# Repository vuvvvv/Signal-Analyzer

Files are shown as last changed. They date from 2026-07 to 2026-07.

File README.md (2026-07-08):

# Signal Analyzer محلل الاشارات
## RTL-SDR Radio Signal Analyzer with AI Detection

<p align="center">
  
</p>

<p align="center">
  
   &nbsp;&nbsp;
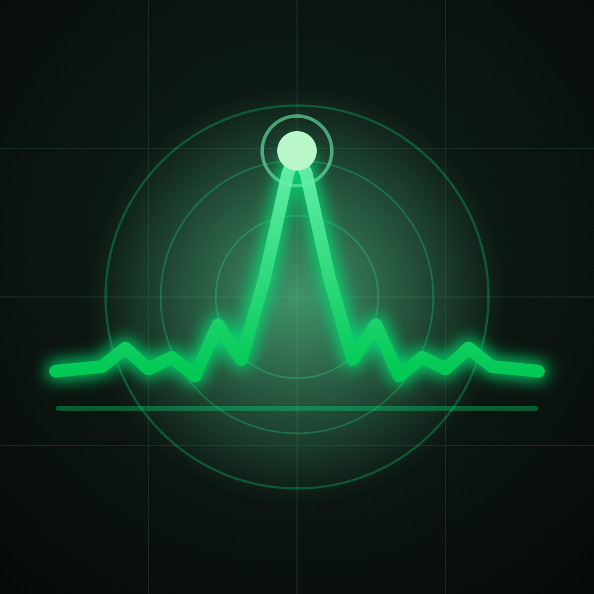
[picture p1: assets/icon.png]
  
   &nbsp;&nbsp;
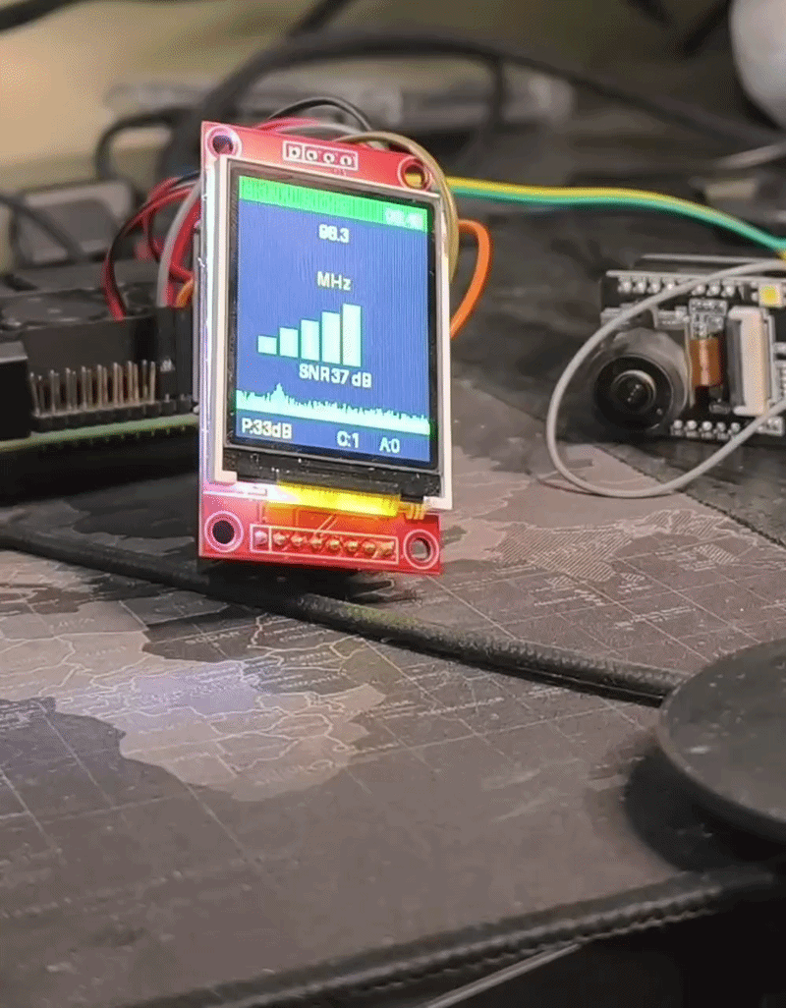
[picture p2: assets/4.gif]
  
</p>
<br><br>

Signal Analyzer is a real-time RF spectrum analyzer built with Flutter, Raspberry Pi, and an RTL SDR receiver. It transforms inexpensive RTL SDR hardware into a portable signal analyzer capable of scanning the RF spectrum, detecting and classifying signals with an AI powered anomaly engine, demodulating supported transmissions, and streaming live spectrum data and detections to a mobile application via WebSocket.

Designed for completely local operation, Signal Analyzer requires no cloud infrastructure, no API keys, and no internet connection. Every component from SDR acquisition and DSP processing to AI inference and visualization runs entirely on the Raspberry Pi and communicates with the Flutter app over your local Wi-Fi network, delivering fast, private, and reliable real-time analysis.

<table align="center">
<tr>
<td align="center">
<b></b><br>
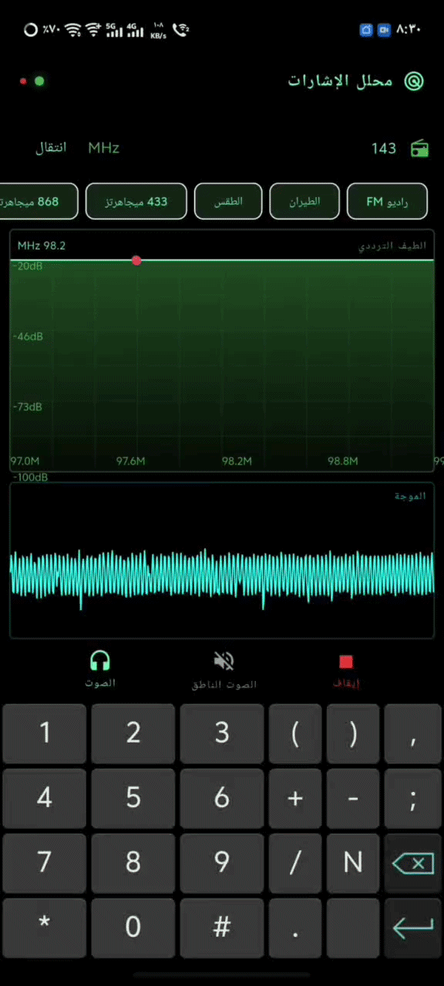
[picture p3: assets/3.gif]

</td>

</tr>
</table>

<br><br>

## Features

- 📊 **Live spectrum & waterfall** — real-time FFT streamed to the Flutter app (MessagePack over WebSocket)
- 🤖 **AI signal detection** — IsolationForest anomaly scoring + band-aware technology matching (Wi-Fi, BLE, LoRa, FM, airband, pagers…)
- 🔊 **On-Pi audio** — WFM / NFM / AM / USB / LSB via a patched `rtl_fm`, CW via `csdr`; audio plays on the Pi's own output
- 🎙️ **Audio classification & Speech-To-Text** — optional TFLite audio classifier and Vosk STT (CPU-only, degrade gracefully if models are missing)
- 🗂️ **RF band database** — table-driven catalogue of allocations, no station names, overlaps handled
- 🖥️ **ST7735 dashboard** — 1.8" LCD on the Pi shows status and alerts, plus a GPIO status LED
- 📼 **IQ capture** — record and compare captures, served over a built-in HTTP endpoint

<br><br>

## How It Works

1. `SdrReader` owns the single RTL-SDR handle and streams raw IQ
2. IQ fans out through drop-oldest queues to the **audio**, **spectrum**, and **AI** workers — no stage can ever block another
3. CPU-heavy AI work (anomaly retraining, audio classification, STT) runs in **separate OS processes** so it never steals time from the real-time path
4. The asyncio event loop pushes results to the Flutter app: AI detections are never dropped, spectrum frames are throttled to only the newest
5. Audio is demodulated and played **on the Pi itself** — no PCM ever crosses the WebSocket, the app only sends control commands

```
SdrReader (RTL-SDR)
   ├── AudioWorker ──► rtl_fm_pipe / csdr ──► Pi speaker
   │        └── AudioClassifierWorker / SttWorker (processes)
   └── SpectrumWorker ──► AiWorker (process, IsolationForest)
                └──► WebSocket ──► Flutter app 📱
```

<br><br>

## Hardware Required

| Component | Model / Spec |
| --- | --- |
| Single-board computer | **Raspberry Pi** (any model with GPIO) |
| SDR receiver | **RTL-SDR dongle** (RTL2832U based) |
| Display | **ST7735 — 1.8 inch — 128×160 pixels** |
| Status LED | Any LED on **GPIO 18** (Pin 12) |
| Audio output | Pi's 3.5mm jack / USB audio (played via `sox`) |
| Phone | Any device running the Flutter app |
| Network | Shared Wi-Fi router **or** phone hotspot |

<br>

## Wiring — ST7735 → Raspberry Pi

| ST7735 Pin | Function | Pi GPIO (BCM) | Notes |
| --- | --- | --- | --- |
| VCC | Power | 3.3V | ⚠️ 3.3V only — never 5V |
| GND | Ground | GND | Common ground |
| SCL / SCLK | SPI Clock | GPIO 11 | Hardware SPI |
| SDA / MOSI | SPI Data | GPIO 10 | Hardware SPI |
| CS | Chip Select  | GPIO 8 | CE0 |
| DC / RS | Data/Command | GPIO 24 | |
| RES / RST  | Reset | GPIO 25 | |
| LED | Status LED | GPIO 18 | Pin 12, with resistor |

💡 The screen runs in **portrait mode (128×160)** and the install script enables hardware SPI for you.

<br><br>

## Raspberry Pi Setup

### 1. Install everything

```bash
cd backend
chmod +x install.sh
./install.sh
```

The script installs system packages, blacklists the DVB kernel driver, enables SPI, builds `csdr` and `rtl_fm_pipe` from source, and sets up the Python venv.

### 2. (Optional) AI extras

Drop the models in `backend/models/` to unlock the extra features — everything works without them:

```
backend/models/audio_classifier.tflite   # audio classification
backend/models/vosk-model-small/         # Speech-To-Text button
```

### 3. Run the server

```bash
source venv/bin/activate
python signal_server.py
```

The WebSocket server listens on port **8765**.

### Prebuilt Modules

Three modules of the analyzer ship as **precompiled native extensions** (`.so`) instead of Python source: `signal_analyzer`, `channel_id`, and `fingerprint_store`. Everything else in the backend is open source — you can read it, modify it, and extend it freely.

Nothing extra to do: the `.so` files are already in `backend/` and Python imports them automatically. `install.sh` verifies they load on your Pi. They are built for **Raspberry Pi OS (64-bit)** with its stock Python — if the check fails on your setup (different architecture or Python version), open an issue with your `uname -m` and `python3 -V` output.

<br><br>

## Flutter App Setup

<table align="center">
<tr>
<td align="center">
<b>الرئيسيه</b><br>
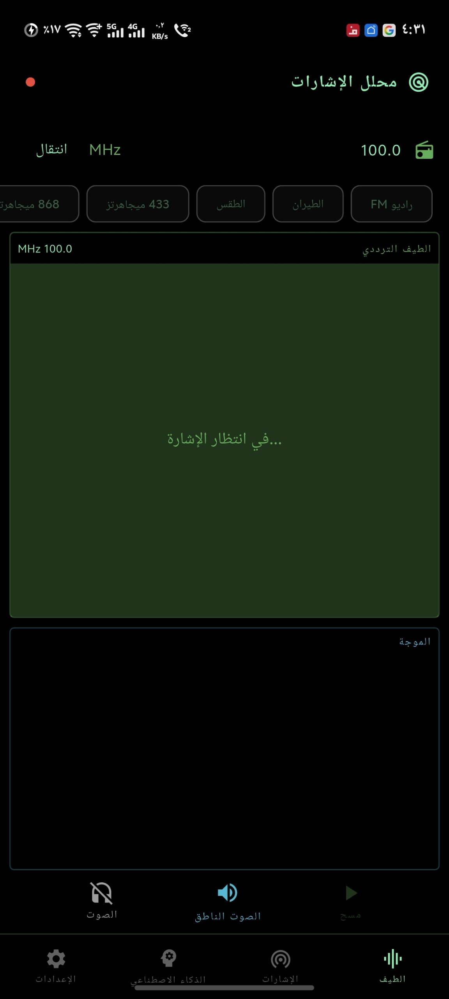
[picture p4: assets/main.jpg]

</td>

<td align="center">
<b>Ai </b><br>
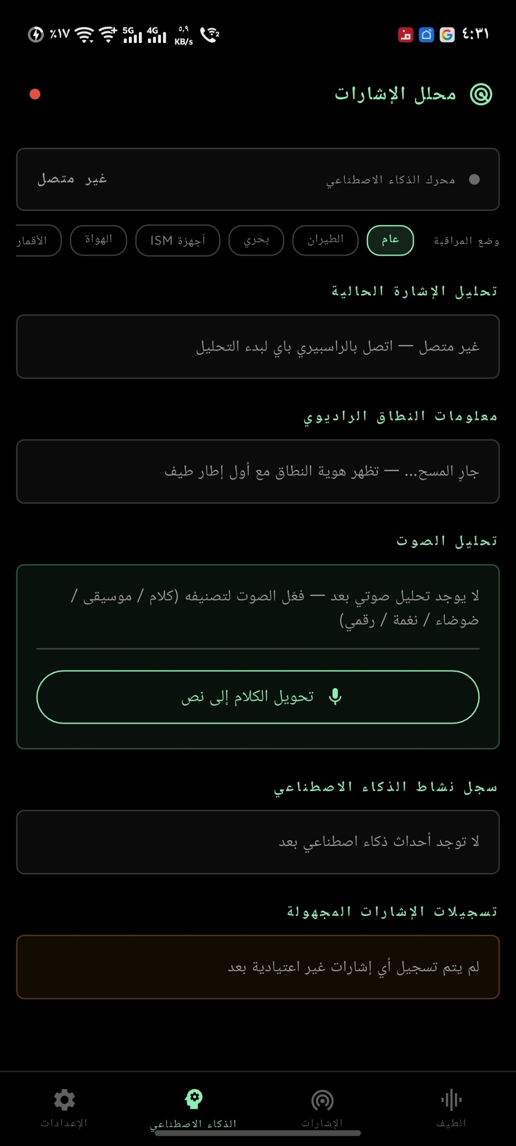
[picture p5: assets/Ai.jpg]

</td>

<td align="center">
<b>الاشارة</b><br>
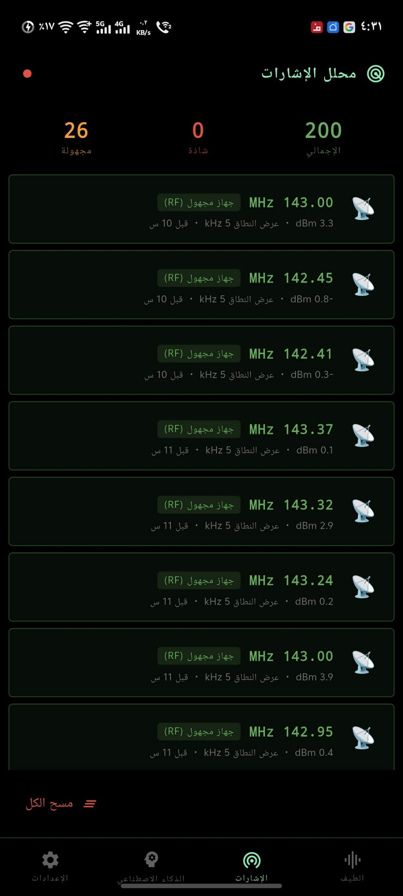
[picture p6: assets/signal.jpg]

</td>

<td align="center">
<b>الاعدادات</b><br>
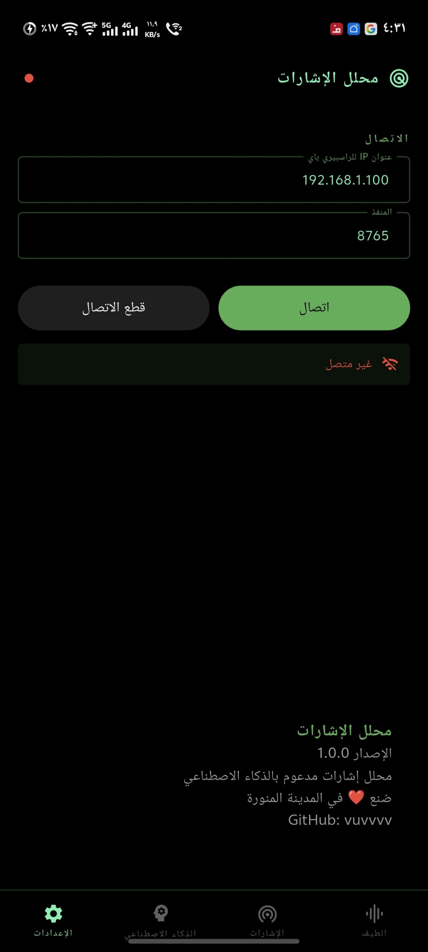
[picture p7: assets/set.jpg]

</td>
</tr>
</table>

<br><br>

### 1. Build & install

```bash
flutter pub get
flutter run
```

### 2. Connect

Open the **Settings** tab and enter your Pi's IP with port `8765`, then start scanning. The **Spectrum**, **Signals**, and **AI** tabs update in real time — with local notifications and TTS alerts for high-priority detections.

<br><br>

## App Screens

| Tab | What it shows |
| --- | --- |
| 📊 Spectrum  | Live FFT / waterfall, frequency tuning, demodulator + audio controls |
| 📡 Signals | Detected signals with band, technology, and SNR |
| 🤖 AI | Anomaly scores, audio classification, Speech-To-Text, captures |
| ⚙️ Settings  | Pi connection, alerts, preferences |

<br><br>

## Pi Server Protocol

| Message | Direction | Description |
| --- | --- | --- |
| `set_freq` | app → Pi | Tune to a frequency |
| `set_demodulator` | app → Pi | WFM / NFM / AM / USB / LSB / CW |
| `start_audio` / `stop_audio` | app → Pi | Toggle on-Pi audio playback |
| `set_volume` / `mute` / `unmute` | app → Pi | Audio control |
| `start_stt` / `stop_stt` | app → Pi  | Toggle Speech-To-Text |
| spectrum / waveform  | Pi → app | Throttled, newest-frame-only |
| AI detections | Pi → app | Priority — never dropped |
<br><br>

## 3D Print Files

A printable enclosure for the Pi + ST7735 build, found in the [`3D/`](3D/) folder:

- [`signalbox.stl`](3D/signalbox.stl) — main box
- [`signalcaver.stl`](3D/signalcaver.stl) — cover

<p align="center">
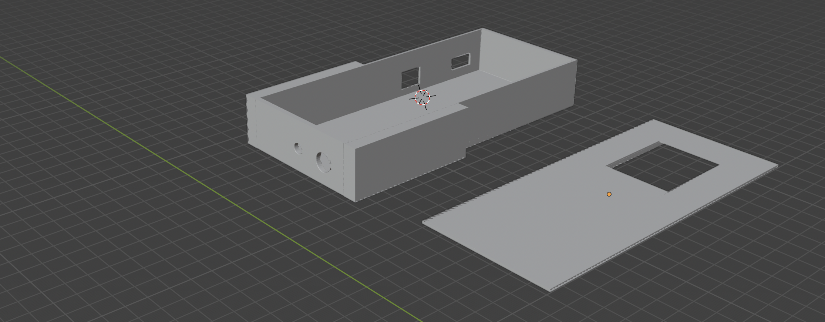
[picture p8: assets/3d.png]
  
</p>

<br><br>

## Project Structure

```
SignalـAnalyzer/
├── 3D/                           # 3D-printable enclosure
│   ├── signalbox.stl             # main box
│   └── signalcaver.stl           # cover
├── lib/                          # Flutter app
│   ├── main.dart
│   ├── screens/
│   │   ├── home_screen.dart
│   │   ├── spectrum_screen.dart
│   │   ├── signals_screen.dart
│   │   ├── ai_screen.dart
│   │   └── settings_screen.dart
│   ├── services/
│   │   └── sdr_service.dart      # WebSocket + msgpack client
│   ├── models/
│   ├── utils/
│   └── widgets/
│       └── spectrum_painter.dart
├── backend/                      # Raspberry Pi server
│   ├── signal_server.py          # WebSocket server + pipeline
│   ├── sdr_reader.py             # RTL-SDR IQ reader
│   ├── spectrum_worker.py        # FFT
│   ├── ai_worker.py              # IsolationForest (own process)
│   ├── signal_analyzer.so        # signal classification engine (prebuilt, closed-source)
│   ├── channel_id.so             # channel/band identity (prebuilt, closed-source)
│   ├── fingerprint_store.so      # signal fingerprint memory (prebuilt, closed-source)
│   ├── band_db.py                # RF allocation database
│   ├── audio_worker.py           # demod pipeline
│   ├── rtl_fm_chain.py           # WFM/NFM/AM/USB/LSB via rtl_fm_pipe
│   ├── csdr_chain.py             # CW via csdr
│   ├── audio_classifier_worker.py
│   ├── stt_worker.py             # Vosk Speech-To-Text
│   ├── capture_manager.py        # IQ captures
│   ├── screen_controller.py      # ST7735 dashboard
│   ├── led_controller.py         # status LED
│   ├── vendor/rtl_fm_pipe.c      # patched rtl_fm (stdin IQ)
│   └── install.sh
└── assets/
```

<br><br>

<p align="center">
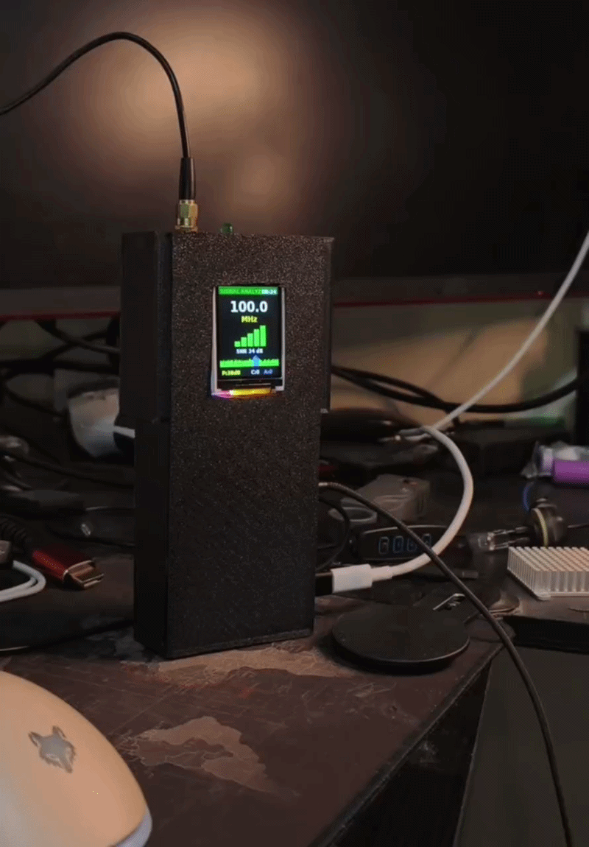
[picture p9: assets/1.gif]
  
</p>

[@vuvvvv](https://github.com/vuvvvv)

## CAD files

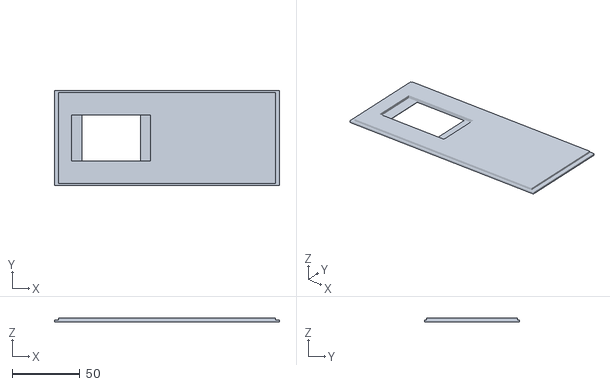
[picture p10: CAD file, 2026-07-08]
3D/signalcaver.stl
165.7 x 70.1 x 3.12

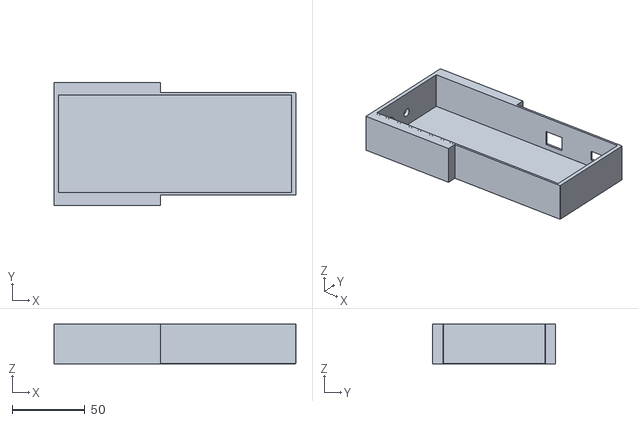
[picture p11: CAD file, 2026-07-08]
3D/signalbox.stl
165.8 x 84.0 x 27.2

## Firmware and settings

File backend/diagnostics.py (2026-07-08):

#!/usr/bin/env python3
"""Standalone diagnostic tool for the FM receive chain (RF -> SDR config ->
IQ samples -> DSP -> audio).

This is intentionally separate from the live server: it opens the RTL-SDR
directly (same device, same settings as `sdr_reader.py`, but no threads,
no queues, no WebSocket) and measures real numbers at every stage so a fix
can be based on measurement instead of guesswork. Run it while the server
(signal_server.py) is stopped, since only one process can hold the dongle.

Usage:
    python3 diagnostics.py --freq 94.0
    python3 diagnostics.py --freq 94.0 --gains auto,20.7,40.2 --ppm 0 --demod WFM
    python3 diagnostics.py --freq 94.0 --out report.json
"""

import argparse
import json
import sys
import time

import numpy as np
from scipy import signal as dsp_signal

from dsp import get_demodulator
from dsp.filters import estimate_carrier_offset
from stage_profiler import StageProfiler

DEFAULT_GAINS = ["auto", 0, 8.7, 19.7, 28.0, 33.8, 40.2, 49.6]
CHANNEL_HALF_BW_HZ = 100_000.0  # matches WFMDemodulator.channel_bw_hz
OFFSET_SEARCH_HALF_BW_HZ = 300_000.0  # wider window: tuner LO error can be hundreds of kHz


def open_sdr(freq_hz: float, sample_rate: float, gain, ppm: int):
    from rtlsdr import RtlSdr

    sdr = RtlSdr()
    sdr.sample_rate = sample_rate
    sdr.center_freq = freq_hz
    if ppm:
        sdr.freq_correction = ppm
    try:
        sdr.gain = gain
    except Exception as e:
        print(f"  ! gain {gain!r} rejected ({e}), falling back to auto")
        sdr.gain = "auto"

    actual = {
        "requested": {"sample_rate": sample_rate, "center_freq": freq_hz, "gain": gain, "ppm": ppm},
        "actual": {
            "sample_rate": sdr.sample_rate,
            "center_freq": sdr.center_freq,
            "gain": sdr.gain,
            "freq_correction": sdr.freq_correction,
        },
    }
    return sdr, actual


def analyze_iq(iq: np.ndarray) -> dict:
    i, q = iq.real, iq.imag
    clip_thresh = 0.98
    clipping_pct = 100.0 * np.mean((np.abs(i) >= clip_thresh) | (np.abs(q) >= clip_thresh))
    dc_i, dc_q = float(np.mean(i)), float(np.mean(q))
    rms_i, rms_q = float(np.sqrt(np.mean(i ** 2))), float(np.sqrt(np.mean(q ** 2)))
    imbalance_db = 20 * np.log10(rms_i / rms_q) if rms_q > 0 else float("inf")
    corr = float(np.corrcoef(i, q)[0, 1]) if np.std(i) > 0 and np.std(q) > 0 else 0.0
    return {
        "clipping_pct": round(clipping_pct, 3),
        "dc_offset_i": round(dc_i, 5),
        "dc_offset_q": round(dc_q, 5),
        "rms_i": round(rms_i, 5),
        "rms_q": round(rms_q, 5),
        "iq_imbalance_db": round(imbalance_db, 2),
        "iq_correlation": round(corr, 4),
    }


def analyze_spectrum(iq: np.ndarray, sample_rate: float, freq_hz: float) -> dict:
    freqs, psd = dsp_signal.welch(iq, fs=sample_rate, nperseg=4096, return_onesided=False)
    freqs = np.fft.fftshift(freqs)
    psd_db = 10 * np.log10(np.fft.fftshift(psd) + 1e-20)

    noise_floor_db = float(np.percentile(psd_db, 20))
    peak_idx = int(np.argmax(psd_db))
    peak_db = float(psd_db[peak_idx])
    peak_freq_offset_hz = float(freqs[peak_idx])
    snr_db = peak_db - noise_floor_db

    in_channel = np.abs(freqs) <= CHANNEL_HALF_BW_HZ
    weights = np.clip(psd_db[in_channel] - noise_floor_db, 0, None)
    if weights.sum() > 0:
        centroid_offset_hz = float(np.sum(freqs[in_channel] * weights) / weights.sum())
    else:
        centroid_offset_hz = 0.0
    suggested_ppm = centroid_offset_hz / freq_hz * 1e6

    # wider search: the strongest carrier may sit hundreds of kHz from the
    # requested center (tuner LO error / quirk), well outside one channel
    wide_offset_hz = estimate_carrier_offset(iq, sample_rate, OFFSET_SEARCH_HALF_BW_HZ) or 0.0

    return {
        "noise_floor_db": round(noise_floor_db, 2),
        "peak_power_db": round(peak_db, 2),
        "wide_search_carrier_offset_hz": round(wide_offset_hz, 1),
        "snr_db": round(snr_db, 2),
        "peak_offset_from_center_hz": round(peak_freq_offset_hz, 1),
        "channel_centroid_offset_hz": round(centroid_offset_hz, 1),
        "suggested_ppm_correction": round(suggested_ppm, 2),
    }


def gain_sweep(freq_hz: float, sample_rate: float, ppm: int, candidate_gains: list) -> list:
    results = []
    for gain in candidate_gains:
        try:
            sdr, _ = open_sdr(freq_hz, sample_rate, gain, ppm)
            iq = sdr.read_samples(64 * 1024)
            sdr.close()
        except Exception as e:
            results.append({"gain": gain, "error": str(e)})
            continue

        power_dbfs = 10 * np.log10(np.mean(np.abs(iq) ** 2) + 1e-20)
        iq_stats = analyze_iq(iq)
        spec_stats = analyze_spectrum(iq, sample_rate, freq_hz)
        results.append({
            "gain": gain,
            "power_dbfs": round(float(power_dbfs), 2),
            "clipping_pct": iq_stats["clipping_pct"],
            "snr_db": spec_stats["snr_db"],
        })
        time.sleep(0.05)
    return results


def audio_diagnostics(sdr, sample_rate: float, demod_name: str, n_chunks: int = 40, chunk_size: int = 8192) -> dict:
    demod = get_demodulator(demod_name)
    demod._build_state(sample_rate)
    warmup = max(5, n_chunks // 4)

    # mirror AudioWorker's one-shot lock: estimate once up front from a real
    # capture, then hold it fixed for the rest of the run (no per-chunk re-lock)
    first_iq = sdr.read_samples(chunk_size)
    offset = estimate_carrier_offset(first_iq, sample_rate, OFFSET_SEARCH_HALF_BW_HZ) or 0.0
    demod.set_freq_offset(offset)
    print(f"  locked carrier offset: {offset:+.0f} Hz")

    discriminator_samples = []
    post_process_samples = []
    pcm_samples = []

    for chunk_idx in range(n_chunks):
        iq = first_iq if chunk_idx == 0 else sdr.read_samples(chunk_size)
        centered = demod._mixer.process(iq)
        filtered = demod._channel_filter.process(centered)
        decimated = filtered[:: demod._decim_factor]
        intermediate_rate = sample_rate / demod._decim_factor

        raw_demod = demod._demodulate(decimated, intermediate_rate)
        post = demod._post_process(raw_demod, intermediate_rate)
        resampled = demod._resampler.process(post)
        pcm = np.clip(resampled * 32767, -32768, 32767).astype(np.int16)

        if chunk_idx >= warmup:
            discriminator_samples.append(raw_demod)
            post_process_samples.append(post)
            pcm_samples.append(pcm)

    disc = np.concatenate(discriminator_samples) if discriminator_samples else np.array([0.0])
    post_all = np.concatenate(post_process_samples) if post_process_samples else np.array([0.0])
    pcm_all = np.concatenate(pcm_samples) if pcm_samples else np.array([0], dtype=np.int16)
    pcm_f = pcm_all.astype(np.float64) / 32767.0

    silence_thresh = 0.01
    clip_thresh = 32760

    return {
        "demodulator": demod.name,
        "discriminator_rms": round(float(np.sqrt(np.mean(disc ** 2))), 5),
        "discriminator_peak": round(float(np.max(np.abs(disc))), 5),
        "post_process_rms": round(float(np.sqrt(np.mean(post_all ** 2))), 5),
        "post_process_peak": round(float(np.max(np.abs(post_all))), 5),
        "audio_rms": round(float(np.sqrt(np.mean(pcm_f ** 2))), 5),
        "audio_peak": int(np.max(np.abs(pcm_all))),
        "clipping_pct": round(100.0 * np.mean(np.abs(pcm_all) >= clip_thresh), 3),
        "silence_pct": round(100.0 * np.mean(np.abs(pcm_f) < silence_thresh), 2),
    }


def chunk_size_sweep(
    freq_hz: float,
    sample_rate: float,
    demod_name: str = "WFM",
    gain=40.2,
    ppm: int = 0,
    sizes: tuple = (2048, 4096, 8192),
    duration_s: float = 3.0,
    queue_depth: int = 3,
) -> list:
    """Measures, not guesses: for each candidate IQ chunk size, runs the
    real demodulator on real captures for `duration_s` seconds and reports
    per-chunk DSP latency (Avg/Max/p99), CPU usage (DSP-time / chunk
    duration — over 1.0 means the chunk can't be processed in real time),
    and how many chunks a drop-oldest queue of depth `queue_depth` would
    have to drop if AudioWorker fell behind by that amount."""
    results = []
    for chunk_size in sizes:
        sdr, _ = open_sdr(freq_hz, sample_rate, gain, ppm)
        demod = get_demodulator(demod_name)
        demod._build_state(sample_rate)

        first_iq = sdr.read_samples(chunk_size)
        offset = estimate_carrier_offset(first_iq, sample_rate, OFFSET_SEARCH_HALF_BW_HZ) or 0.0
        demod.set_freq_offset(offset)

        chunk_duration_s = chunk_size / sample_rate
        profiler = StageProfiler(window=10_000)
        n_chunks = max(1, int(duration_s / chunk_duration_s))
        max_clip = 0
        total_samples = 0

        for i in range(n_chunks):
            iq = first_iq if i == 0 else sdr.read_samples(chunk_size)
            t0 = time.perf_counter()
            pcm = demod.process(iq, sample_rate)
            profiler.record("dsp", time.perf_counter() - t0)
            max_clip += int(np.sum(np.abs(pcm) >= 32760))
            total_samples += len(pcm)

        sdr.close()
        stats = profiler.stats("dsp") or {}
        cpu_ratio = stats.get("avg_ms", 0) / 1000.0 / chunk_duration_s if chunk_duration_s else 0.0
        # simulate how often a queue of this depth would have to drop a
        # chunk if processing fell behind by p99 instead of average
        behind_chunks = max(0, int((stats.get("p99_ms", 0) / 1000.0) // chunk_duration_s))
        simulated_drops = max(0, behind_chunks - queue_depth)

        results.append({
            "chunk_size": chunk_size,
            "chunk_duration_ms": round(chunk_duration_s * 1000, 3),
            "dsp_avg_ms": round(stats.get("avg_ms", 0), 4),
            "dsp_max_ms": round(stats.get("max_ms", 0), 4),
            "dsp_p99_ms": round(stats.get("p99_ms", 0), 4),
            "cpu_ratio": round(cpu_ratio, 3),  # >1.0 means it can't keep up in real time
            "simulated_drops_per_run": simulated_drops,
            "clipping_samples": max_clip,
            "total_audio_samples": total_samples,
            "n_chunks_tested": n_chunks,
        })
        print(f"  chunk_size={chunk_size}: {results[-1]}")
    return results


def print_report(report: dict) -> None:
    print("\n== RTL-SDR Config (requested vs actual) ==")
    print(json.dumps(report["sdr_config"], indent=2))

    print("\n== IQ Sample Health ==")
    print(json.dumps(report["iq_health"], indent=2))

    print("\n== Spectrum / Frequency Offset ==")
    print(json.dumps(report["spectrum"], indent=2))

    print("\n== Gain Sweep ==")
    for row in report["gain_sweep"]:
        print(f"  {row}")

    print("\n== Audio Pipeline Diagnostics ==")
    print(json.dumps(report["audio"], indent=2))


def main() -> int:
    parser = argparse.ArgumentParser(description="FM receive chain diagnostics")
    parser.add_argument("--freq", type=float, required=True, help="frequency in MHz")
    parser.add_argument("--sample-rate", type=float, default=2.4e6)
    parser.add_argument("--gain", default=40.2, help="gain for the main capture ('auto' or a dB value)")
    parser.add_argument("--gains", default=None, help="comma-separated gain list for the sweep")
    parser.add_argument("--ppm", type=int, default=0)
    parser.add_argument("--demod", default="WFM")
    parser.add_argument("--out", default=None, help="optional path to save the report as JSON")
    parser.add_argument(
        "--chunk-sweep", action="store_true",
        help="measure DSP latency/CPU/clipping across IQ chunk sizes 2048/4096/8192 and exit",
    )
    args = parser.parse_args()

    freq_hz = args.freq * 1e6
    gain = args.gain
    if isinstance(gain, str) and gain != "auto":
        gain = float(gain)

    if args.chunk_sweep:
        print(f"Running chunk-size sweep at {args.freq} MHz (2048/4096/8192)...")
        try:
            sweep = chunk_size_sweep(freq_hz, args.sample_rate, args.demod, gain, args.ppm)
        except Exception as e:
            print(f"Failed to run chunk-size sweep: {e}", file=sys.stderr)
            return 1
        print("\n== Chunk Size Sweep ==")
        print(json.dumps(sweep, indent=2))
        if args.out:
            with open(args.out, "w") as f:
                json.dump({"chunk_sweep": sweep}, f, indent=2)
            print(f"\nSaved report to {args.out}")
        return 0

    print(f"Opening RTL-SDR at {args.freq} MHz, sample_rate={args.sample_rate:.0f}, gain={gain}, ppm={args.ppm}...")
    try:
        sdr, sdr_config = open_sdr(freq_hz, args.sample_rate, gain, args.ppm)
    except Exception as e:
        print(f"Failed to open RTL-SDR: {e}", file=sys.stderr)
        return 1

    print("Capturing IQ block for spectrum/IQ-health analysis...")
    iq_block = sdr.read_samples(2 ** 18)
    iq_health = analyze_iq(iq_block)
    spectrum = analyze_spectrum(iq_block, args.sample_rate, freq_hz)

    if args.gains:
        candidate_gains = [g if g == "auto" else float(g) for g in args.gains.split(",")]
    else:
        candidate_gains = DEFAULT_GAINS
    print(f"Running gain sweep over {candidate_gains}...")
    sweep = gain_sweep(freq_hz, args.sample_rate, args.ppm, candidate_gains)

    print(f"Running audio pipeline diagnostics with demodulator={args.demod}...")
    audio = audio_diagnostics(sdr, args.sample_rate, args.demod)

    sdr.close()

    report = {
        "sdr_config": sdr_config,
        "iq_health": iq_health,
        "spectrum": spectrum,
        "gain_sweep": sweep,
        "audio": audio,
    }
    print_report(report)

    if args.out:
        with open(args.out, "w") as f:
            json.dump(report, f, indent=2)
        print(f"\nSaved report to {args.out}")

    return 0


if __name__ == "__main__":
    sys.exit(main())

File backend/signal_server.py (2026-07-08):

#!/usr/bin/env python3
"""
Signal Scope Backend - Raspberry Pi WebSocket Server

Architecture (real-time pipeline, see README in this directory for the
full writeup):

    SdrReader (thread)          -- blocking RTL-SDR reads, nothing else
        |-- audio_queue   (drop-oldest, depth N) --> AudioWorker (thread) --> LocalAudioSink
        |-- spectrum_slot (drop-oldest, depth 1) --> SpectrumWorker (thread)
                                                          |-- ai_in_queue (drop-oldest, depth 1) --> AiWorker (PROCESS)

    There is exactly one RTL-SDR handle, owned by SdrReader, open for as
    long as scanning is active. Audio and spectrum/AI both read off that
    same IQ stream, so spectrum/search and audio always run together —
    starting/stopping audio never touches the device.

    AudioWorker also taps its finished PCM (only while audio is actually
    enabled) into ai_audio_queue (drop-oldest, depth 1) which feeds
    AudioClassifierWorker (a second, separate PROCESS) and, only when a
    client explicitly asked for it, SttWorker.

    Every worker hands its finished output to this module via a plain
    callback, which bridges it onto the asyncio event loop
    (`loop.call_soon_threadsafe`). The event loop owns a single prioritized
    sender: AI detections are sent as soon as they arrive and are never
    dropped; spectrum/waveform are throttled and always reflect only the
    newest frame, since stale visuals aren't worth the bandwidth. Audio
    classification results and captures are lower priority still — see
    `_sender_loop`.

No stage can block another: the reader never waits on a queue (drop-oldest
everywhere upstream of it), and CPU-heavy AI work (RF anomaly retraining,
audio classification, speech-to-text) all run in separate processes/
threads so none of it can steal GIL time from the SDR/spectrum/audio/
network real-time path. Every AI-adjacent stage is a pure consumer: if it
falls behind, its queue just drops old data — it can never block or slow
down the pipeline feeding it.

Audio is *not* streamed to clients. AudioWorker (audio_worker.py) feeds IQ
into rtl_fm_pipe (rtl_fm_chain.py — a patched, otherwise-unmodified build
of rtl-sdr's own rtl_fm.c) for WFM/NFM/AM/USB/LSB, and into csdr
(csdr_chain.py) for CW (the one mode real rtl_fm has no -M for). No
demodulator is written for this project; PCM is written straight to
LocalAudioSink, which plays it on the Pi's own audio output via a local
`play` subprocess. Flutter only ever sends control commands (start_audio/
stop_audio/set_freq/set_demodulator/set_volume/mute/unmute) — no PCM
crosses the WebSocket.
"""

from __future__ import annotations

import asyncio
import logging
import os
import queue
import threading
import time
from datetime import datetime

import msgpack
import numpy as np
import websockets

from ai_worker import AiWorker
from audio_classifier_worker import AudioClassifierWorker
from audio_worker import AudioWorker
from capture_manager import CaptureManager
from captures_http import CapturesHttpServer
from droppable_queue import drain_queue, put_dropping_oldest
from led_controller import LedController
from local_audio import LocalAudioSink
from screen_controller import ScreenController
from sdr_reader import SdrReader
from spectrum_worker import SpectrumWorker
from stt_worker import SttWorker

logging.basicConfig(level=logging.INFO)
log = logging.getLogger(__name__)

HOST = "0.0.0.0"
PORT = 8765
# 2.4 MS/s (old value) sits near the FC0013's practical USB/ADC limit —
# confirmed via a side-by-side IQ capture (iq_compare.py) on this exact
# hardware/antenna/station: same carrier-lock accuracy, same DC-spike
# size, but measurably (and audibly) noisier than capturing at 1.02 MS/s —
# the rate rtl_fm itself uses on this dongle ("Sampling at 1020000 S/s" in
# its own log).
SAMPLE_RATE = 1_020_000.0
# Hard tuner limits for THIS dongle's FC0013: asking librtlsdr for a
# frequency the PLL can't lock (e.g. 949 MHz) doesn't just fail — it
# leaves the device in a bad state and the process segfaults. Reject
# out-of-range requests before they ever reach the hardware.
# Override via SIGNAL_SCOPE_TUNER_RANGE="14:948" (MHz) for other tuners.
_range = os.environ.get("SIGNAL_SCOPE_TUNER_RANGE", "14:948").split(":")
TUNER_MIN_MHZ, TUNER_MAX_MHZ = float(_range[0]), float(_range[1])
NUM_SAMPLES = 8 * 1024  # ~8.0ms/chunk at this rate — matches rtl_fm's own "Buffer size: 8.03ms"
AUDIO_QUEUE_DEPTH = 3  # ~25ms of look-ahead before the reader drops audio chunks
VIZ_SEND_INTERVAL = 1 / 12  # spectrum/waveform refresh rate sent to clients


class SdrServer:
    def __init__(self):
        self.led = LedController(gpio_pin=18)
        self.screen = ScreenController()
        self.clients: set = set()
        self.loop: asyncio.AbstractEventLoop | None = None

        # Cross-thread hand-off queues
        self.audio_in_queue: "queue.Queue" = queue.Queue(maxsize=AUDIO_QUEUE_DEPTH)
        self.spectrum_slot: "queue.Queue" = queue.Queue(maxsize=1)
        self.ai_audio_queue: "queue.Queue" = queue.Queue(maxsize=1)  # AudioWorker -> audio tap bridge

        # Outbound (asyncio-side) state
        self.signal_out: asyncio.Queue = asyncio.Queue()
        self.status_out: asyncio.Queue = asyncio.Queue()
        self.audio_ai_out: asyncio.Queue = asyncio.Queue()  # lowest priority: audio class. + captures
        self._latest_spectrum: dict | None = None
        self._latest_waveform: dict | None = None
        self._latest_audio_pcm: bytes | None = None
        self._wake_event: asyncio.Event | None = None

        _gain_override = os.environ.get("SIGNAL_SCOPE_GAIN")
        _gain = _gain_override if _gain_override == "auto" else (float(_gain_override) if _gain_override else 40.2)
        self.reader = SdrReader(
            SAMPLE_RATE, NUM_SAMPLES, self.audio_in_queue, self.spectrum_slot, gain=_gain
        )
        self.audio_sink = LocalAudioSink()
        self.audio_worker = AudioWorker(
            SAMPLE_RATE, self.audio_in_queue, self.audio_sink, ai_tap_queue=self.ai_audio_queue
        )
        self.ai_worker = AiWorker(self._on_detection)
        # SpectrumWorker feeds the AI process directly: its mp.Queue
        # (maxsize=1, drop-oldest via put_dropping_oldest) IS the ai_in
        # slot. There is no intermediate plain Queue — a previous refactor
        # left one in between with nothing consuming it, which silently
        # starved the RF analyzer of every frame.
        self.ai_in_queue = self.ai_worker.in_queue
        self.spectrum_worker = SpectrumWorker(
            self.spectrum_slot, self.ai_in_queue, self._on_spectrum, self._on_waveform
        )
        self.audio_classifier_worker = AudioClassifierWorker(self._on_audio_classification)
        self.capture_manager = CaptureManager()
        self.stt_worker = SttWorker(self._on_stt_text)
        self.captures_http = CapturesHttpServer(self.capture_manager.base_dir)
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

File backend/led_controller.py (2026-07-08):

"""LED Controller - GPIO18 (Pin 12)

Aircraft-beacon style: brightness ramps up and down smoothly using PWM,
like a plane's beacon light. If software PWM is unavailable (some Pi 5 /
rpi-lgpio setups), falls back to plain on/off blinking so the LED always
works. Pulsing runs on a background thread so callers never block.
"""

import math
import threading
import time
import logging

log = logging.getLogger(__name__)

try:
    import RPi.GPIO as GPIO
    _HAS_GPIO = True
except ImportError:
    _HAS_GPIO = False
    log.warning("RPi.GPIO not available (not on Pi?)")


class LedController:
    PWM_FREQ = 200        # Hz, flicker-free
    FADE_STEPS = 80       # brightness steps per fade in/out (more = smoother)

    def __init__(self, gpio_pin: int = 18):
        self.pin = gpio_pin
        self._pwm = None
        self._lock = threading.Lock()
        self._pulses_pending = 0
        self._beacon = False
        self._pulse_interval = 0.5
        self._stop = threading.Event()
        self._wake = threading.Event()
        if _HAS_GPIO:
            GPIO.setmode(GPIO.BCM)
            GPIO.setup(self.pin, GPIO.OUT, initial=GPIO.LOW)
            try:
                self._pwm = GPIO.PWM(self.pin, self.PWM_FREQ)
                self._pwm.start(0)
                # Verify PWM actually accepts duty changes; some backends
                # only fail here, not at construction.
                self._pwm.ChangeDutyCycle(0)
                log.info("LED: software PWM active (smooth beacon mode)")
            except Exception as e:
                log.warning(f"LED: PWM unavailable ({e}), using on/off fallback")
                self._pwm = None
        self._thread = threading.Thread(target=self._run, name="led-pulse", daemon=True)
        self._thread.start()
        # Startup self-test: one visible pulse confirms wiring/config
        self.blink(times=1, interval=0.3)

    def _set_brightness(self, percent: float):
        if not _HAS_GPIO:
            return
        try:
            if self._pwm:
                self._pwm.ChangeDutyCycle(max(0.0, min(100.0, percent)))
            else:
                GPIO.output(self.pin, GPIO.HIGH if percent >= 50 else GPIO.LOW)
        except Exception as e:
            log.error(f"LED: set brightness failed: {e}")

    def on(self):
        self._set_brightness(100)

    def off(self):
        self._set_brightness(0)

    def blink(self, times: int = 1, interval: float = 0.2):
        """Queue smooth beacon pulses; returns immediately."""
        with self._lock:
            self._pulses_pending += times
            self._pulse_interval = interval
        self._wake.set()

    def start_beacon(self, interval: float = 1.2):
        """Pulse continuously (aircraft beacon) until stop_beacon()."""
        with self._lock:
            self._beacon = True
            self._pulse_interval = interval
        self._wake.set()

    def stop_beacon(self):
        with self._lock:
            self._beacon = False
        self.off()

    def _run(self):
        while not self._stop.is_set():
            self._wake.wait()
            if self._stop.is_set():
                break
            with self._lock:
                beacon = self._beacon
                if not beacon and self._pulses_pending <= 0:
                    self._wake.clear()
                    continue
                if not beacon:
                    self._pulses_pending -= 1
                interval = self._pulse_interval
            try:
                self._pulse(fade_time=max(interval, 0.15))
            except Exception as e:
                log.error(f"LED: pulse failed: {e}")

    def _pulse(self, fade_time: float):
        """One smooth breath: sine ramp 0 -> 100 -> 0 over 2*fade_time.
        In fallback (no PWM) mode this degrades to a clean on/off blink."""
        if self._pwm is None:
            self._set_brightness(100)
            time.sleep(fade_time)
            self._set_brightness(0)
            time.sleep(fade_time)
            return
        step_delay = fade_time / self.FADE_STEPS
        # Full breath as one cosine cycle: eased at both the dark and
        # bright ends, then squared (gamma) so the fade looks linear to
        # the eye — LEDs otherwise appear to snap on early in the ramp.
        total = self.FADE_STEPS * 2
        for i in range(total + 1):
            if self._stop.is_set():
                return
            level = (1 - math.cos(math.pi * i / self.FADE_STEPS)) / 2  # 0->1->0
            self._set_brightness(100 * level * level)
            time.sleep(step_delay)
        # Clear dark gap so the LED visibly rests fully off between breaths
        time.sleep(fade_time * 0.5)

    def cleanup(self):
        self._stop.set()
        self._wake.set()
        self._thread.join(timeout=2)
        if _HAS_GPIO:
            try:
                if self._pwm:
                    self._pwm.stop()
            finally:
                GPIO.cleanup(self.pin)

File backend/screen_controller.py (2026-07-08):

"""
ST7735 Screen Controller — PORTRAIT mode (128x160)
Wiring: VCC=3.3V, GND, CLK=GPIO11, MOSI=GPIO10, CS=GPIO8, DC=GPIO24, RST=GPIO25

Layout (top to bottom):
  - Header bar: app name + clock
  - Big frequency readout (large font) + "MHz"
  - Signal-strength bars (phone-style, from spectrum SNR) + dB value
  - Mini spectrum strip
  - Info lines: peak power, clients connected, anomaly count
"""

import logging
import time
from datetime import datetime

log = logging.getLogger(__name__)

try:
    from luma.core.interface.serial import spi
    from luma.lcd.device import st7735
    from PIL import Image, ImageDraw, ImageFont
    _HAS_LCD = True
except ImportError:
    _HAS_LCD = False
    log.warning("luma.lcd not available")

_FONT_PATHS = [
    "/usr/share/fonts/truetype/dejavu/DejaVuSans-Bold.ttf",
    "/usr/share/fonts/truetype/dejavu/DejaVuSans.ttf",
]


def _load_font(size: int):
    for path in _FONT_PATHS:
        try:
            return ImageFont.truetype(path, size)
        except Exception:
            continue
    return ImageFont.load_default()


class ScreenController:
    # Portrait: panel's native 128x160 orientation
    WIDTH = 128
    HEIGHT = 160

    DASHBOARD_INTERVAL = 1.0  # seconds between dashboard redraws
    ALERT_HOLD = 4.0          # keep an alert on screen this long before dashboard resumes

    def __init__(self):
        self.device = None
        self._last_dashboard = 0.0
        self._alert_until = 0.0
        self._anomaly_count = 0
        if _HAS_LCD:
            try:
                serial = spi(port=0, device=0, gpio_DC=24, gpio_RST=25)
                # Panel native geometry is 160x128 (proven working config).
                # rotate=1 turns it 90° so the framebuffer becomes 128x160
                # portrait — do NOT swap width/height here, luma does that.
                self.device = st7735(
                    serial, width=self.HEIGHT, height=self.WIDTH, rotate=1, bgr=True
                )
                log.info("ST7735 screen initialized (portrait 128x160)")
            except Exception as e:
                log.error(f"Screen init failed: {e}")
        if _HAS_LCD:
            self._font_big = _load_font(26)
            self._font_med = _load_font(14)
            self._font_small = _load_font(10)

    def _make_image(self) -> tuple:
        img = Image.new("RGB", (self.WIDTH, self.HEIGHT), "black")
        draw = ImageDraw.Draw(img)
        return img, draw

    def _display(self, img):
        if self.device:
            self.device.display(img)

    def _center_x(self, draw, text: str, font) -> int:
        w = draw.textlength(text, font=font)
        return int((self.WIDTH - w) / 2)

    def show_boot(self):
        if not _HAS_LCD:
            return
        img, draw = self._make_image()
        draw.text((self._center_x(draw, "SIGNAL", self._font_big), 40),
                  "SIGNAL", font=self._font_big, fill="green")
        draw.text((self._center_x(draw, "ANALYZER", self._font_big), 70),
                  "ANALYZER", font=self._font_big, fill="green")
        draw.text((self._center_x(draw, "Ready", self._font_small), 110),
                  "Ready", font=self._font_small, fill=(0, 180, 0))
        now = datetime.now().strftime("%H:%M:%S")
        draw.text((self._center_x(draw, now, self._font_small), 125),
                  now, font=self._font_small, fill="gray")
        self._display(img)

    # ---- main live view -------------------------------------------------

    def show_dashboard(self, powers: list, center_mhz: float, clients: int = 0):
        """Portrait dashboard. Throttled internally — safe to call at spectrum rate."""
        if not _HAS_LCD:
            return
        now = time.monotonic()
        if now < self._alert_until or now - self._last_dashboard < self.DASHBOARD_INTERVAL:
            return
        self._last_dashboard = now

        img, draw = self._make_image()

        # Header bar
        draw.rectangle([(0, 0), (self.WIDTH - 1, 13)], fill=(0, 40, 0))
        draw.text((3, 2), "SIGNAL ANALYZER", font=self._font_small, fill="green")
        clock = datetime.now().strftime("%H:%M")
        draw.text((self.WIDTH - draw.textlength(clock, font=self._font_small) - 3, 2),
                  clock, font=self._font_small, fill="white")

        # Big frequency readout
        freq_txt = f"{center_mhz:.1f}"
        draw.text((self._center_x(draw, freq_txt, self._font_big), 20),
                  freq_txt, font=self._font_big, fill="white")
        draw.text((self._center_x(draw, "MHz", self._font_med), 50),
                  "MHz", font=self._font_med, fill=(0, 200, 255))

        # Signal strength: SNR = peak above median noise floor
        peak_db = snr = 0.0
        bars = 0
        if powers:
            sorted_p = sorted(powers)
            noise = sorted_p[len(sorted_p) // 2]
            peak_db = max(powers)
            snr = peak_db - noise
            for th in (3, 8, 15, 22, 30):
                if snr >= th:
                    bars += 1

        # Phone-style bars (5 bars, increasing height)
        bx, base_y = 32, 106
        for i in range(5):
            h = 8 + i * 7
            x0 = bx + i * 14
            box = [(x0, base_y - h), (x0 + 10, base_y)]
            if i < bars:
                color = "red" if bars <= 1 else ("yellow" if bars <= 2 else "lime")
                draw.rectangle(box, fill=color)
            else:
                draw.rectangle(box, outline=(60, 60, 60))
        snr_txt = f"SNR {snr:.0f} dB"
        draw.text((self._center_x(draw, snr_txt, self._font_small), 109),
                  snr_txt, font=self._font_small, fill="white")

        # Mini spectrum strip
        strip_top, strip_h = 122, 20
        if powers:
            n = len(powers)
            min_p = min(powers)
            rng = max(max(powers) - min_p, 1)
            for x in range(self.WIDTH):
                idx = int(x * n / self.WIDTH)
                norm = (powers[idx] - min_p) / rng
                bar = int(norm * strip_h)
                draw.line([(x, strip_top + strip_h - bar), (x, strip_top + strip_h)],
                          fill=(0, 255, 0) if norm < 0.7 else (255, 60, 60))
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
